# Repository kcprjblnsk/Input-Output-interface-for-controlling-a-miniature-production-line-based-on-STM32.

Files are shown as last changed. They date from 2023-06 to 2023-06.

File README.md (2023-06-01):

# Input-Output-interface-for-controlling-a-miniature-production-line-based-on-STM32. // Interfejs Wejść/Wyjść Mikrokontrolera do STM32F429 DISCOVERY w celu sterowania miniaturową linią produkcyjną 

Ten projekt ma na celu zintegrowanie mikrokontrolera STM32F429 DISCOVERY z interfejsem wejść/wyjść w celu oddzielenia sygnałów, połączeń elektrycznych i sterowania elementami wykonawczymi w prototypie miniaturowej linii produkcyjnej.

## Przegląd Projektu

Projekt wykorzystuje płytę STM32F429 DISCOVERY jako główny komponent do sterowania linią produkcyjną. Dzięki połączeniu z własnym interfejsem Wejście/Wyjście, udaje się izolować różne sygnały i połączenia elektryczne, co gwarantuje efektywne zarządzanie i sterowanie elementami linii produkcyjnej.

## Konfiguracja Sprzętu

Płytę STM32F429 DISCOVERY wpina się w interfejs, wykorzystując do tego dwa, dwurzędowe, 64-pinowe złącza. Wszystkie sygnały i napięcia układu są do niego doprowadzone. W tym celu zastosowano złącza 4-, 14- i 18-pinowe, co zapewnia łatwe utrzymanie systemu.

## Utrzymanie

Ta konstrukcja zapewnia prosty sposób na serwisowanie systemu dzięki łatwo dostępnym i modularnym złączom. Wszelkie wymagane naprawy lub modyfikacje systemu mogą być przeprowadzane szybko i sprawnie.

## Wnioski

Projekt oferuje eleganckie rozwiązanie do sterowania miniaturową linią produkcyjną przy użyciu wszechstronnego mikrokontrolera STM32F429 DISCOVERY. Oferuje to doskonałą skalowalność dla projektów tego typu i otwiera drzwi do wielu możliwości dalszego rozwoju i rozbudowy.

## Licencja

Ten projekt jest objęty [licencją MIT](LICENSE) (jeśli dotyczy).

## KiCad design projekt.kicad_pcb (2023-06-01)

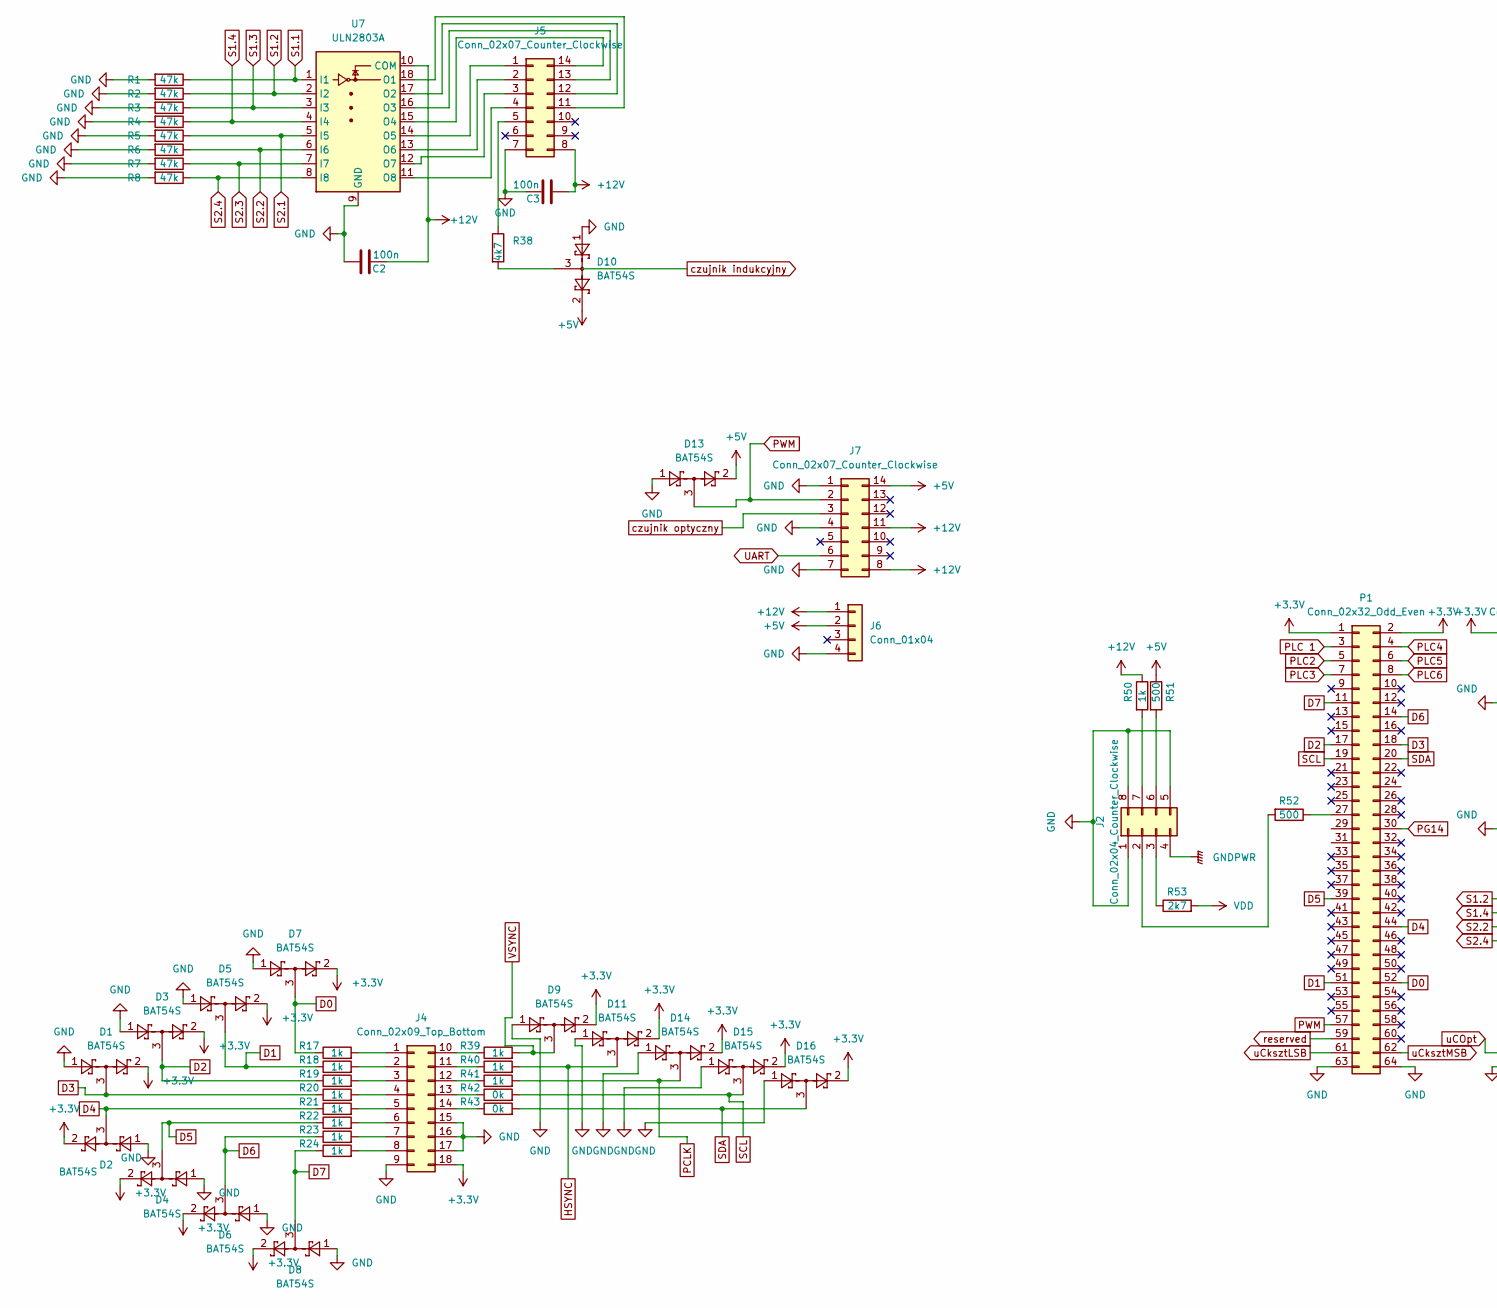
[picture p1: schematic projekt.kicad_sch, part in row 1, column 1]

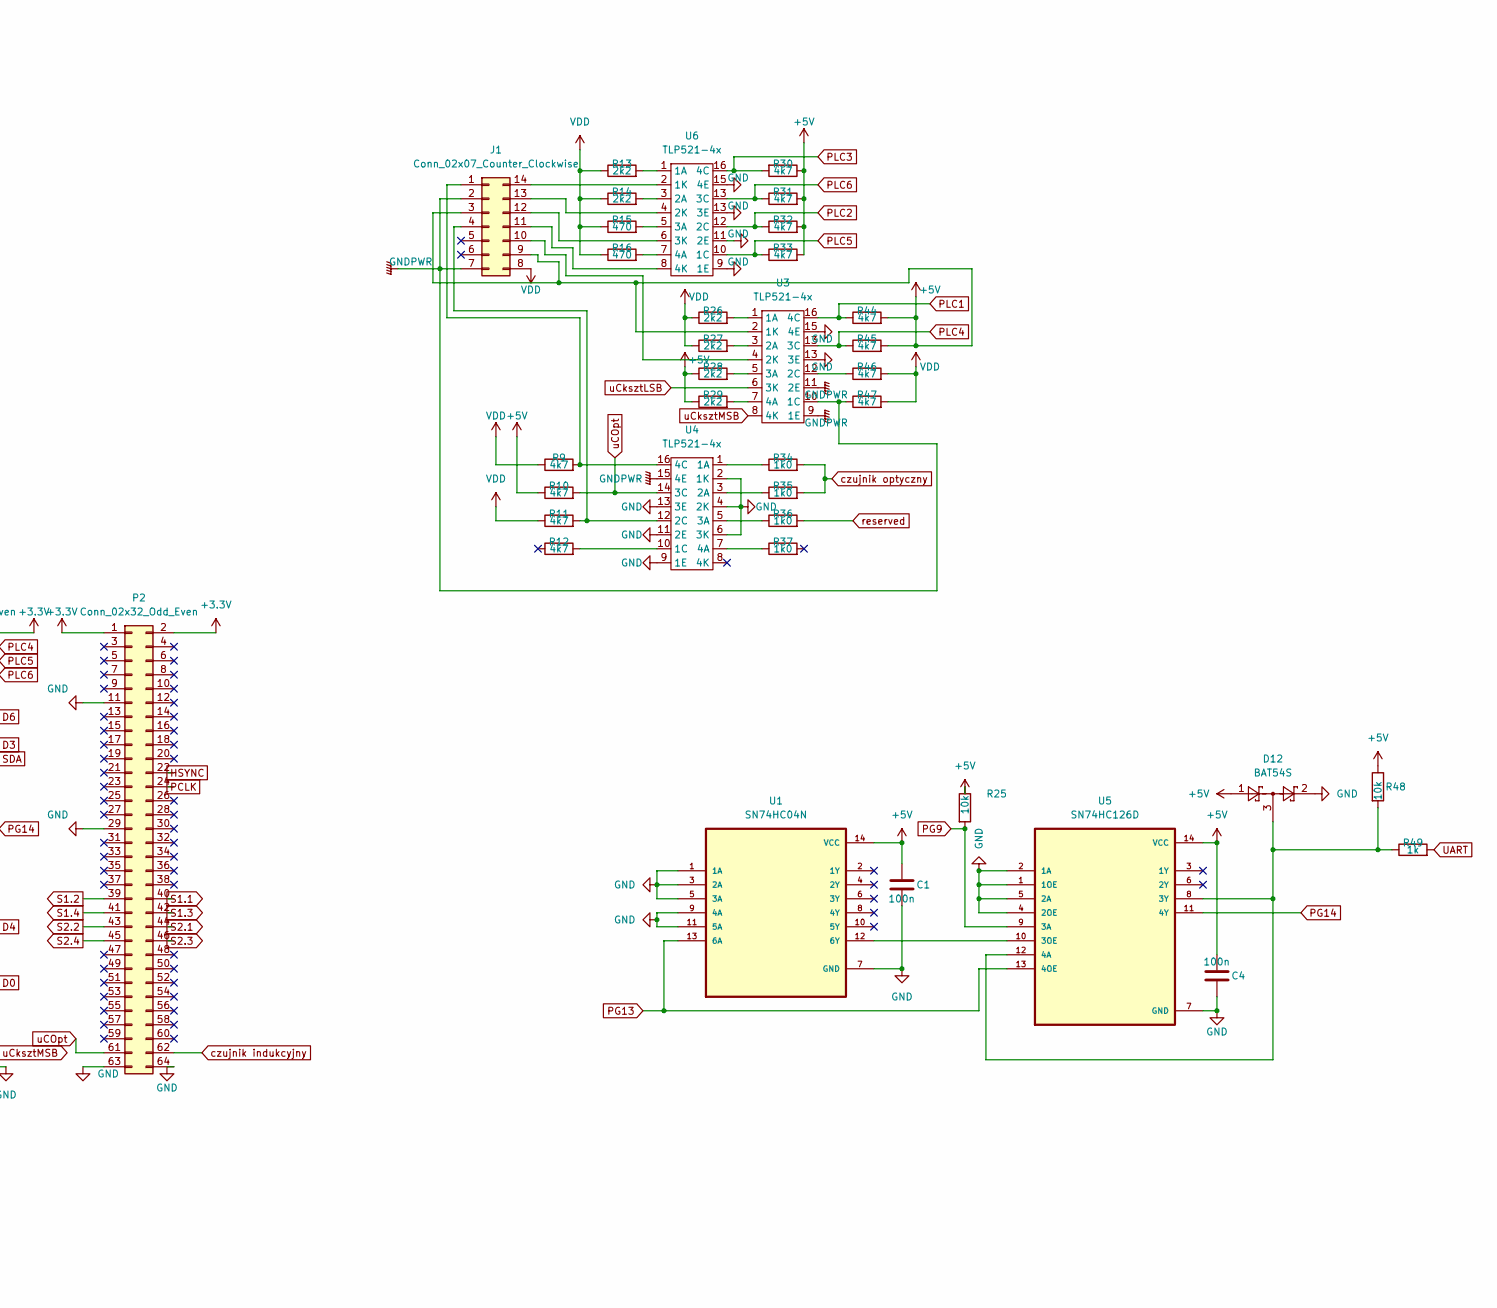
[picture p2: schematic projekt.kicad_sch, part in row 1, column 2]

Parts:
C1, C2, C3, C4: 100n; C_0805_2012Metric
D1, D2, D3, D4, D5, D6, D7, D8, D9, D10, D11, D12, D13, D14, D15, D16: BAT54S; SOT-23
J1, J5, J7: Conn_02x07_Counter_Clockwise; Molex_Micro-Fit_3.0_43045-1412_2x07_P3.00mm_Vertical
J2: Conn_02x04_Counter_Clockwise; PinSocket_2x04_P2.54mm_Vertical
J4: Conn_02x09_Top_Bottom; Molex_Micro-Fit_3.0_43045-1812_2x09_P3.00mm_Vertical
J6: Conn_01x04; Molex_Micro-Latch_53253-0470_1x04_P2.00mm_Vertical
P1, P2: Conn_02x32_Odd_Even; PinSocket_2x32_P2.54mm_Vertical
R1, R2, R3, R4, R5, R6, R7, R8: 47k; R_0805_2012Metric
R9, R10, R11, R12, R30, R31, R32, R33, R38, R44, R45, R46, R47: 4k7; R_0805_2012Metric
R13, R14, R26, R27, R28, R29: 2k2; R_0805_2012Metric
R15, R16: 470; R_0805_2012Metric
R17, R18, R19, R20, R21, R22, R23, R24, R39, R40, R41, R49, R50: 1k; R_0805_2012Metric
R25, R48: 10k; R_0805_2012Metric
R34, R35, R36, R37: 1k0; R_0805_2012Metric
R42, R43: 0k; R_0805_2012Metric
R51, R52: 500; R_0805_2012Metric
R53: 2k7; R_0805_2012Metric
U1: SN74HC04N; DIP-14_W7.62mm
U3, U4, U6: TLP521-4x; DIP-16_W7.62mm
U5: SN74HC126D; DIP-14_W7.62mm
U7: ULN2803A; DIP-18_W7.62mm

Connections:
+3.3V: D1.2, D2.2, D3.2, D4.2, D5.2, D6.2, D7.2, D8.2, D9.2, D11.2, D14.2, D15.2, D16.2, J4.18, P1.1, P1.2, P2.1, P2.2
+5V: C1.1, C4.2, D10.2, D12.1, D13.2, J1.3, J1.9, J6.2, J7.14, R10.1, R25.1, R28.1, R29.1, R30.1, R31.2, R32.2, R33.2, R44.2, R45.2, R48.1, R51.1, U1.14 (VCC), U3.2 (1K), U5.14 (VCC)
+12V: C2.2, C3.2, J5.8, J6.1, J7.8, J7.11, R50.1, U7.10 (COM)
D0: D7.3, P1.52, R17.1
D1: D5.3, P1.51, R18.1
D2: D3.3, P1.17, R19.1
D3: D1.3, P1.18, R20.1
D4: D2.3, P1.44, R21.1
D5: D4.3, P1.39, R22.1
D6: D6.3, P1.14, R23.1
D7: D8.3, P1.11, R24.1
GNDPWR: J1.2, J1.7, J2.4, R47.1, U3.9 (1E), U3.10 (1C), U3.11 (2E), U4.15 (4E)
HSYNC: D11.3, P2.22, R40.2
unnamed: D10.3, R38.2
unnamed: D12.3, R48.2, R49.1, U5.8 (3Y), U5.12 (4A)
unnamed: J1.1, R9.2, U4.16 (4C)
unnamed: J1.4, R11.2, U4.12 (2C)
unnamed: J1.10, U3.4 (2K)
unnamed: J1.11, U6.8 (4K)
unnamed: J1.12, U6.6 (3K)
unnamed: J1.13, U6.4 (2K)
unnamed: J1.14, U6.2 (1K)
unnamed: J2.2, R52.2
unnamed: J2.3, R53.1
unnamed: J2.6, R51.2
unnamed: J2.7, R50.2
unnamed: J4.1, R17.2
unnamed: J4.2, R18.2
unnamed: J4.3, R19.2
unnamed: J4.4, R20.2
unnamed: J4.5, R21.2
unnamed: J4.6, R22.2
unnamed: J4.7, R23.2
unnamed: J4.8, R24.2
unnamed: J4.10, R39.1
unnamed: J4.11, R40.1
unnamed: J4.12, R41.1
unnamed: J4.13, R42.1
unnamed: J4.14, R43.1
unnamed: J5.1, U7.14 (O5)
unnamed: J5.2, U7.13 (O6)
unnamed: J5.3, U7.12 (O7)
unnamed: J5.4, U7.11 (O8)
unnamed: J5.5, R38.1
unnamed: J5.11, U7.18 (O1)
unnamed: J5.12, U7.17 (O2)
unnamed: J5.13, U7.16 (O3)
unnamed: J5.14, U7.15 (O4)
unnamed: P1.27, R52.1
unnamed: R12.2, U4.10 (1C)
unnamed: R13.2, U6.1 (1A)
unnamed: R14.2, U6.3 (2A)
unnamed: R15.2, U6.5 (3A)
unnamed: R16.2, U6.7 (4A)
unnamed: R26.2, U3.1 (1A)
unnamed: R27.2, U3.3 (2A)
unnamed: R28.2, U3.5 (3A)
unnamed: R29.2, U3.7 (4A)
unnamed: R34.1, U4.1 (1A)
unnamed: R35.1, U4.3 (2A)
unnamed: R36.1, U4.5 (3A)
unnamed: R37.1, U4.7 (4A)
unnamed: R46.1, U3.12 (2C)
unnamed: U1.12 (6Y), U5.10 (3OE)
PCLK: D14.3, P2.24, R41.2
PG9: R25.2, U5.9 (3A)
PG13: U1.13 (6A), U5.13 (4OE)
PG14: P1.30, U5.11 (4Y)
PLC1: R44.1, U3.16 (4C)
PLC2: P1.5, R32.1, U6.12 (2C)
PLC3: P1.7, R30.2, U6.16 (4C)
PLC5: P1.6, R33.1, U6.10 (1C)
PLC 1: P1.3
PWM: D13.3, J7.2, P1.57
S1.1: P2.40, R1.1, U7.1 (I1)
S1.2: P2.39, R2.1, U7.2 (I2)
S1.3: P2.42, R3.1, U7.3 (I3)
S1.4: P2.41, R4.1, U7.4 (I4)
S2.1: P2.44, R5.1, U7.5 (I5)
S2.2: P2.43, R6.1, U7.6 (I6)
S2.3: P2.46, R7.1, U7.7 (I7)
S2.4: P2.45, R8.1, U7.8 (I8)
SCL: D15.3, P1.19, R42.2
SDA: D16.3, P1.20, R43.2
UART: J7.6, R49.2
VDD: J1.8, R9.1, R11.1, R13.1, R14.1, R15.1, R16.1, R26.1, R27.1, R46.2, R47.2, R53.2
VSYNC: D9.3, R39.2
czujnik indukcyjny: P2.62
czujnik optyczny: J7.3, R34.2, R35.2
reserved: P1.59, R36.2
uCOpt: P2.61, R10.2, U4.14 (3C)
uCksztLSB: P1.61, U3.6 (3K)
uCksztMSB: P1.62, U3.8 (4K)

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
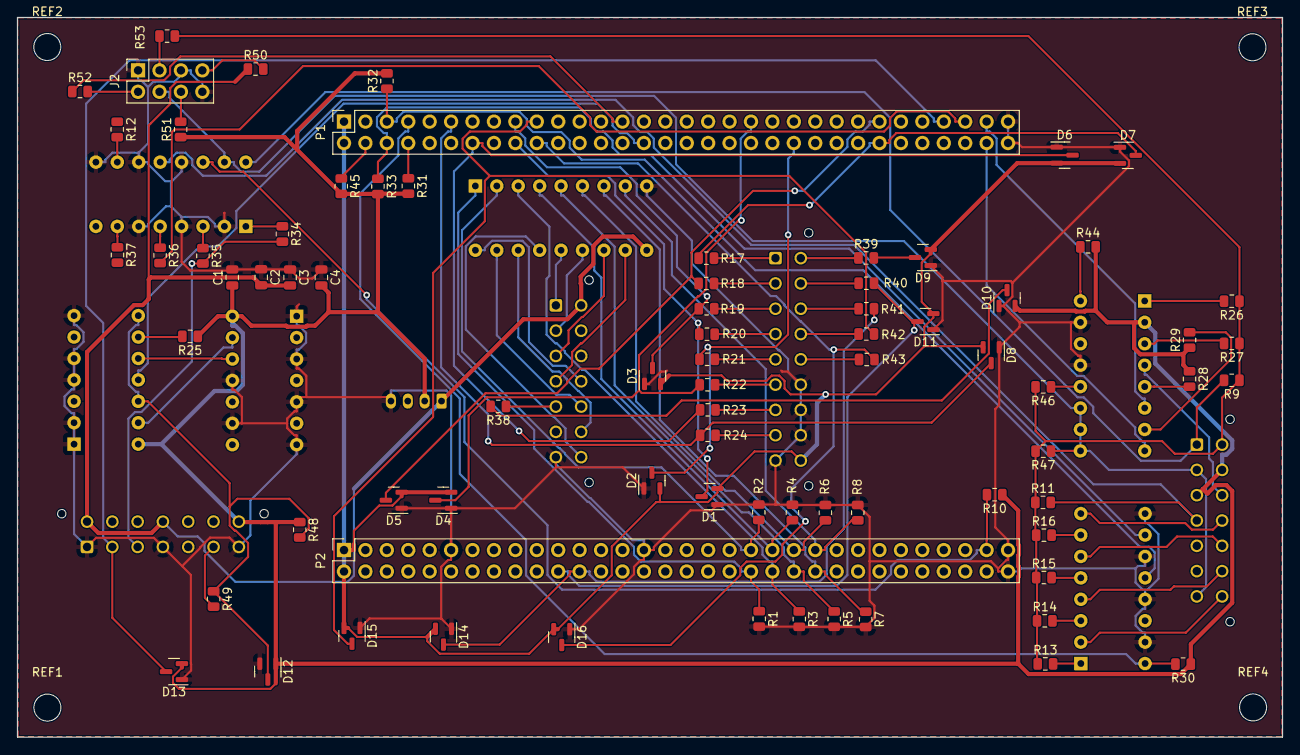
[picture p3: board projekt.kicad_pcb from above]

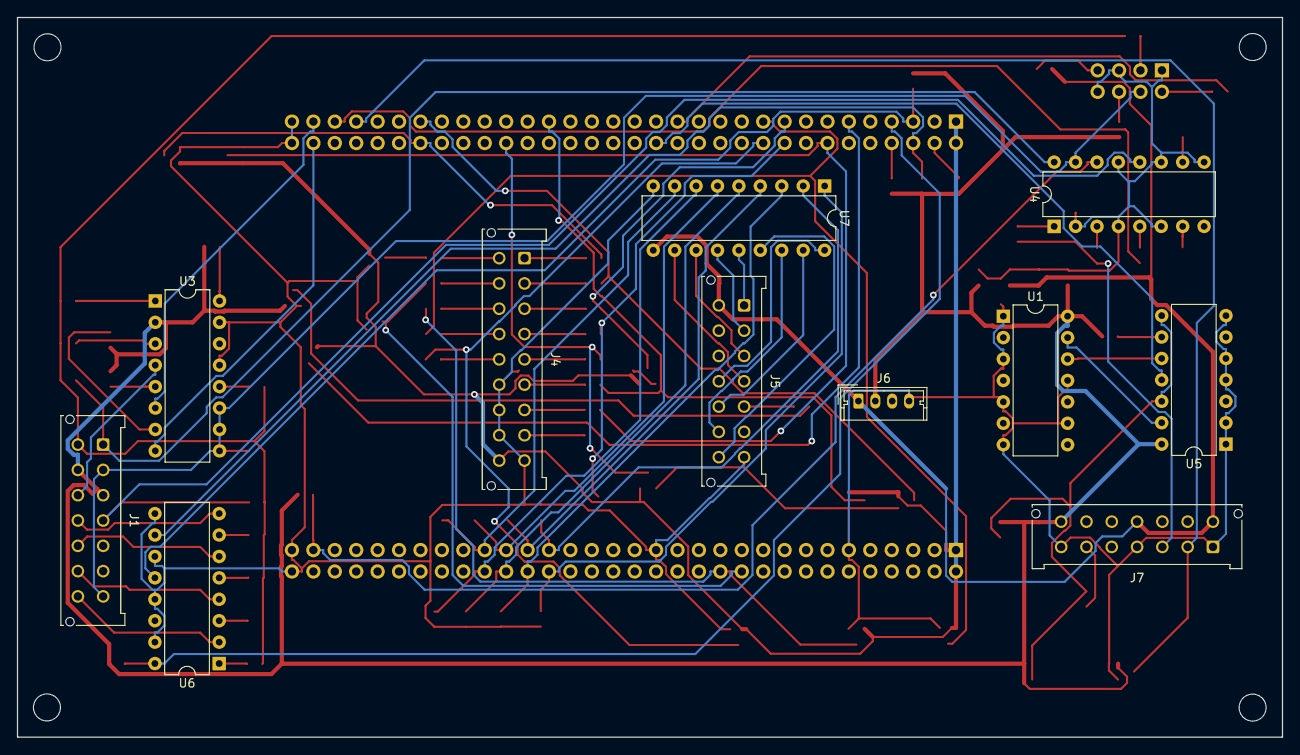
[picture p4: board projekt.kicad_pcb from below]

Board: 2 copper layers, 150.0 x 85.3 mm, 91 parts (11 on the bottom side), 94 nets.

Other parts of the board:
REF1, REF2, REF3, REF4: MountingHole_3.2mm_M3
